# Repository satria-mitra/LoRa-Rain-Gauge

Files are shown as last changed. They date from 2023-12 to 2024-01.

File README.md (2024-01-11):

# <div style="text-align: center;" markdown="1">LoRa Rain Gauge</div>

This repository contains an Arduino sketch for a rain gauge system that utilizes LoRa communication, RTC for timestamping, and an SD card for data logging.

*CASA0016:MDB*\
Satria Mitra Utama

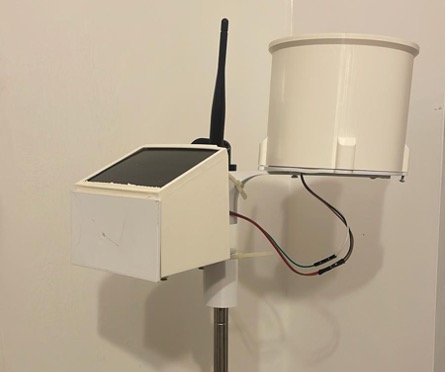
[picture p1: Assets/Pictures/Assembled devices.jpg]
Rain Gauge

# Dependancies
## Hardware Requirements
1. Arduino MKR board with LoRa connectivity
2. DS3231 RTC module
3. SD card module
4. Reed switch for rainfall measurement
5. 5mm Neodymum magnet
6. Printed Rain Gauge
7. 25mm screw with diameter 2mm
7. Lot of wires

### Optional Hardwares
1. Lipo Battery
2. Solar Panel
3. Adafruit Solar Charger

## Software
### Arduino Libraries
1. [RTCLib](https://www.arduino.cc/reference/en/libraries/rtclib/)
2. [MKRWAN](https://www.arduino.cc/reference/en/libraries/mkrwan/)
3. Wire
4. SD
5. SPI

### Node Red
1. [Node-Red Dashboard lib](https://flows.nodered.org/node/node-red-dashboard)

# Getting Started
1. **Connections**: Wire up the components according to the provided pin configurations. 

| No | Hardware | Hardware Pin | Arduino MKR Pin |
|----|---|---|---|
|1 | RTC | VCC |VCC |
| | | GND | GND |
| | | SCL | SCL/12 |
| | | SDA | SDA/11 |
|2 | Sd card  | VCC |VCC |
| | | GND | GND |
| | | MOSI | 8/MOSI |
| | | MISO | 10/MISO |
| | | SCK | 7 |
|3 | Reed switch| SW1 | 6 |
| | | VCC | VCC |
| | | GND | GND |
|4 | Charger | JST + | JST + |
| | | JST- | JST - |

2. **Rain Gauge**:
   - Print these files using PLA (not waterproof) or PETG(waterproof) filament 
     - rain_gauge-can.stl
     - rain_gauge-bucket.stl
     - rain_gauge-base.stl
   - Insert your 5mm neodymum magnet into the side hole of bucket
   - Use long shaft/screw to insert the bucket into the base
   - Plug the reed switch module into base. Final piece of Rain Gauge should looks like this
   
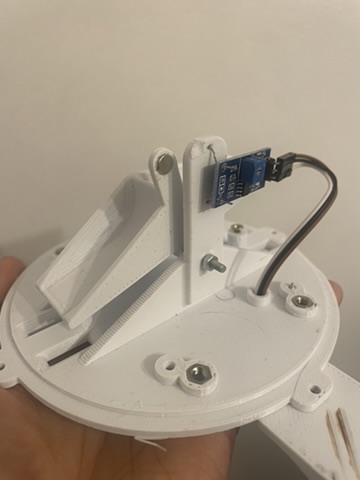
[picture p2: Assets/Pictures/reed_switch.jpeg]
   

2. **Libraries**: Install the necessary libraries (Wire, RTClib, MKRWAN, SPI, SD) in the Arduino IDE.
3. **TTN Application**:
   - Sign up for The Things Network
   - Select your region and [create your application on TTN console](https://www.thethingsindustries.com/docs/integrations/adding-applications/)
   - Plug your Arduino MKRWAN and run a script from Arduino IDE>Examples>MKRWAN>First Configuration, take a note on your DevUI
   - [Register your End Device on TTN Console ](https://workshops.cetools.org/codelabs/CASA0016-Workshop-4/index.html?index=..%2F..casa0016#6)
   - Create a file named __arduino_secrets.h__ on the same folder of Arduino LoRa Transmitter scripts and copy paste your appEui and appKey from TTN Console

     ```
     const char *appEui = "0000000000000000";
     const char *appKey = "<APP_KEY>";
     ``` 
4. Upload the scripts of Transmitter and see live data on TTN Console
5. If you can see your data, congratulations, if not please do see Troubleshooting sections
6. [Install Node-Red](https://nodered.org/docs/getting-started/) on your Raspberry PI or on your PC
7. [Install Node-Red Dashboard library](https://flows.nodered.org/node/node-red-dashboard)
8. Import Node-Red json files configuration from Scripts>Node-Red
9. See the payload on the debug message on Node-red. You can modify or create your own dashboard. Done

# Functionality
### RTC Setup
- Sets up and initializes the DS3231 RTC module for accurate timekeeping.
- Handles RTC power loss scenarios by setting the time using the sketch compilation time if power is lost.

### Rain Measurement
- Monitors rainfall using a reed switch and software debouncing to count pulses accurately.
- Resets accumulated rainfall at midnight to start afresh.

### LoRa Communication and Data Logging
- Sends rain gauge data via LoRaWAN to TTN at regular intervals.
- Logs data (date, time, accumulated rainfall) onto an SD card in a CSV format for local storage.

### Usage
- Monitor the Serial Monitor to observe real-time data and system status.
- Access the `rain.txt` file on the SD card for detailed logged rain gauge data.

## Troubleshooting
- If encountering issues during LoRa connection, ensure proper positioning for signal reception.
- Check your appKey and appEui on TTN Console and your aduino_secrets.h
- Verify wiring connections and component compatibility.
- Dont forget to attach your antenna

## Future Work
- Use low power library
- Design a watertight enclosure

## Reflective learning
- Prototype and iterate to make it better
- Outdoor device needs a waterproof and watertight material

## License
This project is licensed under the MIT License.

## Credits
- Dusan DJ for his awesome tipping buckets

## Acknowledgements
- Arduino community
- Libraries used: RTClib, MKRWAN, SD
- Node Red

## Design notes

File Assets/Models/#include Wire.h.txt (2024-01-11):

#include <Wire.h>
#include <RTClib.h>
#include <MKRWAN.h>
#include <ArduinoLowPower.h>
#include <SPI.h>
#include <SD.h>

// Secret file for storing AppEUI and Appkey of TTN App
#include "arduino_secrets.h"

#define debugSerial Serial

RTC_DS3231 rtc;

// SD card settings
const int chipSelect = 7 ;

// Reed Switch settings
const int reedSwitchPin = 4;
unsigned long lastDebounceTime = 0;
unsigned long debounceDelay = 150; // Adjusted according to pulse on Logic Analyzer

// Var for rain
const float rainTipVolume = 0.2; // mm
volatile int pulseCount = 0;
double   accumulatedRainfall = 0.0;

LoRaModem modem;

// Timer interval in milliseconds (60 seconds)
unsigned long previousMillis = 0;
const unsigned long interval = 600000;

// Variables to store the formatted date and time
char  formattedDate[11];
char  formattedTime[9];

File dataFile;

void setRTC() {
  if (! rtc.begin()) {
    Serial.println("Couldn't find RTC");
    Serial.flush();
    return;
  }

  if (rtc.lostPower()) {
    Serial.println("RTC lost power, let's set the time!");
    // When time needs to be set on a new device, or after a power loss, the
    // following line sets the RTC to the date & time this sketch was compiled
    rtc.adjust(DateTime(F(__DATE__), F(__TIME__)));
    // This line sets the RTC with an explicit date & time, for example to set
    // January 21, 2014 at 3am you would call:
    //rtc.adjust(DateTime(2023, 12, 10, 20, 12, 0));
  }
  // When time needs to be re-set on a previously configured device, the
  // following line sets the RTC to the date & time this sketch was compiled
   //rtc.adjust(DateTime(F(__DATE__), F(__TIME__)));
  // This line sets the RTC with an explicit date & time, for example to set
  // January 21, 2014 at 3am you would call:
  //rtc.adjust(DateTime(2023, 12, 13, 10, 38, 0));
}

void displayDateTime() {
  DateTime now = rtc.now();
  
  // Format date and time
  sprintf(formattedDate, "%04d-%02d-%02d", now.year(), now.month(), now.day());
  sprintf(formattedTime, "%02d:%02d:%02d", now.hour(), now.minute(), now.second());
     
  // Print JSON payload
  Serial.print("date :");
  Serial.println(formattedDate);
  Serial.print("time :");
  Serial.println(formattedTime);
}

void countPulse() {
  // Implement software debouncing
  if (millis() - lastDebounceTime > debounceDelay) {
    pulseCount++; // Increment the pulse count
    float rainCounted = pulseCount * rainTipVolume;
    pulseCount = 0;
    accumulatedRainfall += rainCounted;
    debugSerial.println(accumulatedRainfall);

  }
  lastDebounceTime = millis();
}

void resetRain() {
  DateTime now = rtc.now();
  if (now.hour() == 0 && now.minute() == 00 && now.second() == 0) {
  accumulatedRainfall = 0.0;
  }
}

void publishMessages() {
  DateTime now = rtc.now();
  // Format date and time
  sprintf(formattedDate, "%04d-%02d-%02d", now.year(), now.month(), now.day());
  sprintf(formattedTime, "%02d:%02d:%02d", now.hour(), now.minute(), now.second());

  uint16_t rainInt = accumulatedRainfall*10;

  // Payload message
  byte payload[4];
  payload[0] = highByte(rainInt);
  payload[1] = lowByte(rainInt);
  //payload[2] = highByte(formattedDate);
  //payload[3] = lowByte(formattedDate);

  debugSerial.print("Rain: ");
  debugSerial.print(accumulatedRainfall);
  debugSerial.print("mm at: ");
  debugSerial.print(formattedTime);
  debugSerial.print(" on ");
  debugSerial.println(formattedDate);

  // open the file. note that only one file can be open at a time,
  // so you have to close this one before opening another.
  dataFile = SD.open("rain.txt", FILE_WRITE);

  if (dataFile) {
    dataFile.print(formattedDate);
    dataFile.print(",");
    dataFile.print(formattedTime);
    dataFile.print(",");
    dataFile.println(accumulatedRainfall);
    Serial.println("Data saved");

    dataFile.close();
  } else {
    // if the file didn't open, print an error:
    Serial.println("error opening rain_gauge.txt");
  }

  modem.beginPacket();
  modem.write(payload, sizeof(payload));
  int err = modem.endPacket(true);
  if (err > 0) {
    Serial.println("Message sent correctly!");
  } else {
    Serial.println("Error sending message");
  }
}

void sendPayload() {
  DateTime now = rtc.now();
  if (now.second() == 0) {
    if (millis() - previousMillis >= interval || previousMillis == 0) {
      publishMessages();
      previousMillis = millis(); // Update the previousMillis variable
    }
  } else {
    previousMillis = 0; // Reset previousMillis if it's not at 00 seconds
  }
}
void initModem() {
  // change this to your regional band (eg. US915, AS923, ...)
  if (!modem.begin(EU868)) {
    Serial.println("Failed to start module");
  }

  Serial.print("Your device EUI is: ");
  Serial.println(modem.deviceEUI());

  int connected = modem.joinOTAA(appEui, appKey);
  if (!connected) {
    Serial.println("Something went wrong; are you indoor? Move near a window and retry");
  }
}

void initSDCard() {
  Serial.print("Initializing SD card...");

  if (!SD.begin(7)) {
    Serial.println("initialization failed!");
    return;
  }
  Serial.println("initialization done.");
}

void setup() {
  debugSerial.begin(9600);

    // Wait a maximum of 10s for Serial Monitor
  while (!debugSerial && millis() < 10000);

  initSDCard();
  initModem();
  setRTC();
  displayDateTime(); 
  pinMode(reedSwitchPin, INPUT_PULLUP);
  attachInterrupt(digitalPinToInterrupt(reedSwitchPin), countPulse, FALLING);

}

void loop() {
  // Your code might perform other tasks here, but for rain measurement, we'll focus on the interrupt
  sendPayload();
  resetRain();
  // We're relying on the interrupt to count rain pulses, so this loop might remain empty
}

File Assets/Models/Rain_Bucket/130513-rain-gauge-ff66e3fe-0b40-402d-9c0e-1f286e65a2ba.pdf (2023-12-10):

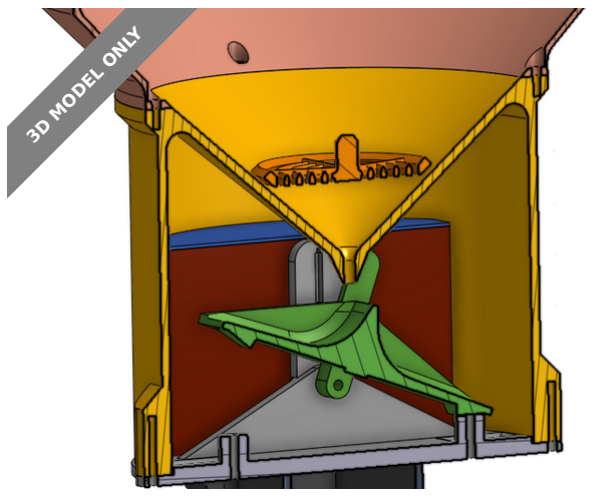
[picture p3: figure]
3D MODEL ONLY

## Summary

Tipping bucket rain gauge with reed switch contact for measuring rainfall

Hobby & Makers (https://www.printables.com/model?categoryId=48) | > | Electronics (https://www.printables.com/model?categoryId=52)
Tags: diy | sensor | rain | raingauge | tippingbucket

srazkomer

Print your own rain gauge for measuring rainfall. Add some microcontroller like arduino or esp and you can gather and chart the daily rainfall in home automation system like OpenHAB or HomeAsisstant.

Description

There are three options how to use it:

put microcontroller inside the can into inside box or
put microcontroller into outside box under the rain gauge or just use wiring from reed switch to microcontroller on better accessible place

Use round magnet 5x2mm together with magnetic reed switch to count impulses. One impuls from reed switch equals 0.2 mm of rainfall. It is possible to adjust the amount a bit with the adjusting screws under the bucket (see the picture)

DusanJ (https://www.printables.com/social/17868/about)

## Rain gauge

VIEW IN BROWSER (https://www.printables.com/model/130513-rain-gauge)

updated 27. 4. 2022 | published 7. 2. 2022

1.
2.
3.

# Model files

Printing tips

Everything is designed to be printed without supports. I recommend to use 0.6mm nozzle for bigger parts. I printed everything with PETG and then painted it with gray UV resistant color paint.

bucket - print on side with magnet holder
can - print upside down

Assembling

Screw the can with top ring with four M3x6 or M3x8. Glue the magnet into bucket, connect reed switch (be carefull not to brake it) and test if the bucket can move smoothly and if the switch is generating correct impulses.

At the end screw together the can with base with four M3x8 screws.

Don't forget to put the strainer into can to avoid jamming the small hole with leaves or insect.

•
•

rain_gauge-base.stl

rain_gauge-base-drop_edge.stl

rain_gauge-bucket.stl

rain_gauge-can.stl

# Other files

- MySensors (mysensors.org) based rain sensor adapted to work on battery
- MySensors (mysensors.org) based rain and anemometer sensor

rain_gauge-top_ring.stl

rain_gauge-holder_square_profile_20x20.stl

rain_gauge-box_outside.stl

rain_gauge-box_inside.stl

rain_gauge-box_inside_cap.stl

rain_gauge-strainer.stl

mysensorsrainbattery.ino

mysensorsanemorain.ino

## License

This work is licensed under a
Creative Commons (4.0 International License)

Attribution (http://creativecommons.org/licenses/by/4.0/)

✖ | Sharing without ATTRIBUTION
✔ | Remix Culture allowed
✔ | Commercial Use
✔ | Free Cultural Works
✔ | Meets Open Definition

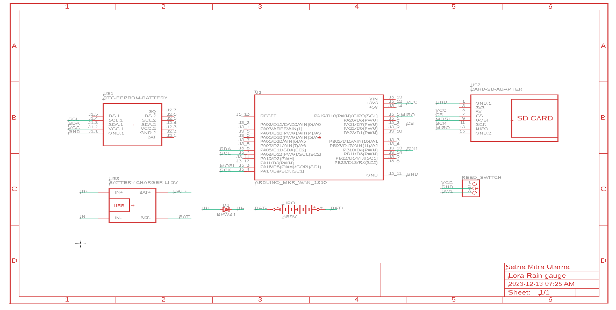
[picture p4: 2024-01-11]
Assets/Pictures/Schematics.png

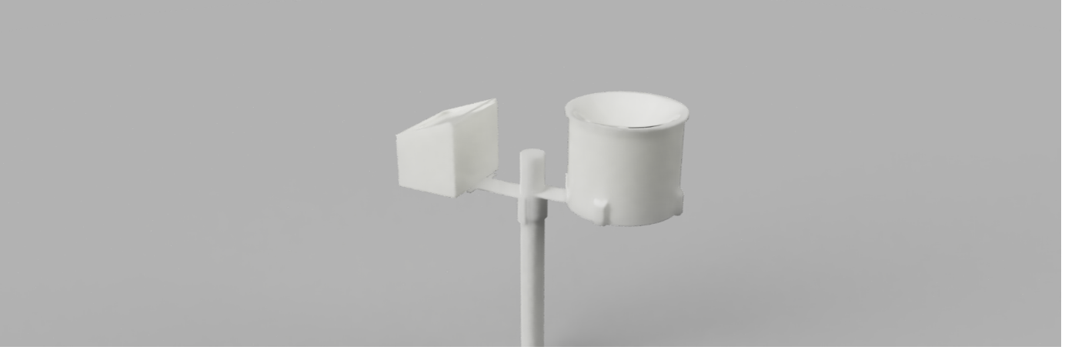
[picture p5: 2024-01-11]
Assets/Pictures/design concept.png

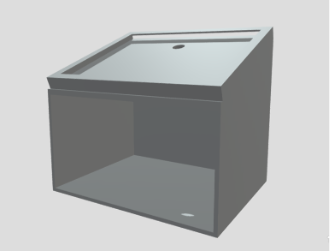
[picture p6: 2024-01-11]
Assets/Pictures/Enclosure.png

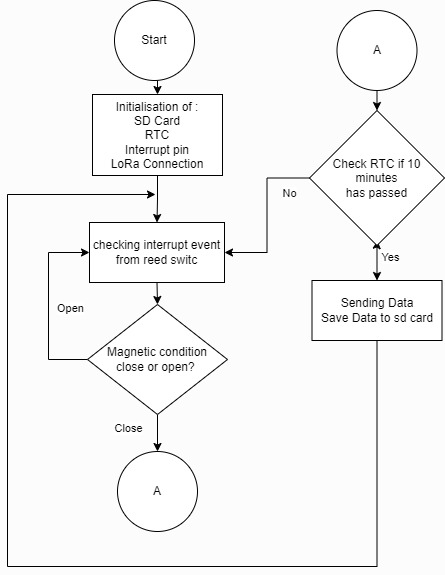
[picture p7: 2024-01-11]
Assets/Diagram/logic diagram (6).jpg

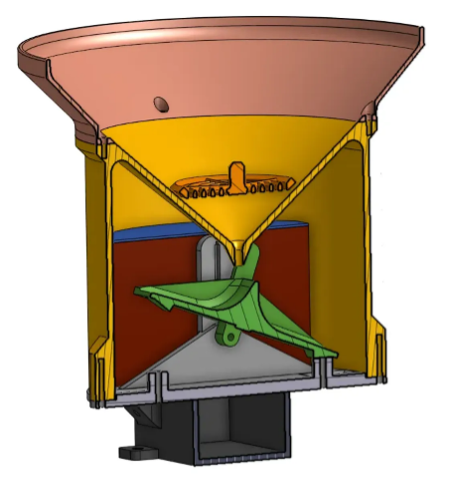
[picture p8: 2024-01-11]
Assets/Pictures/Tipping_bucket.png

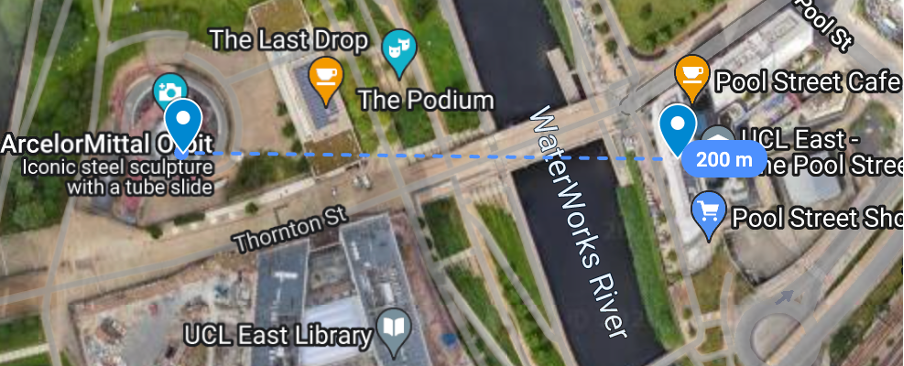
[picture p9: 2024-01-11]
Assets/Pictures/map.png

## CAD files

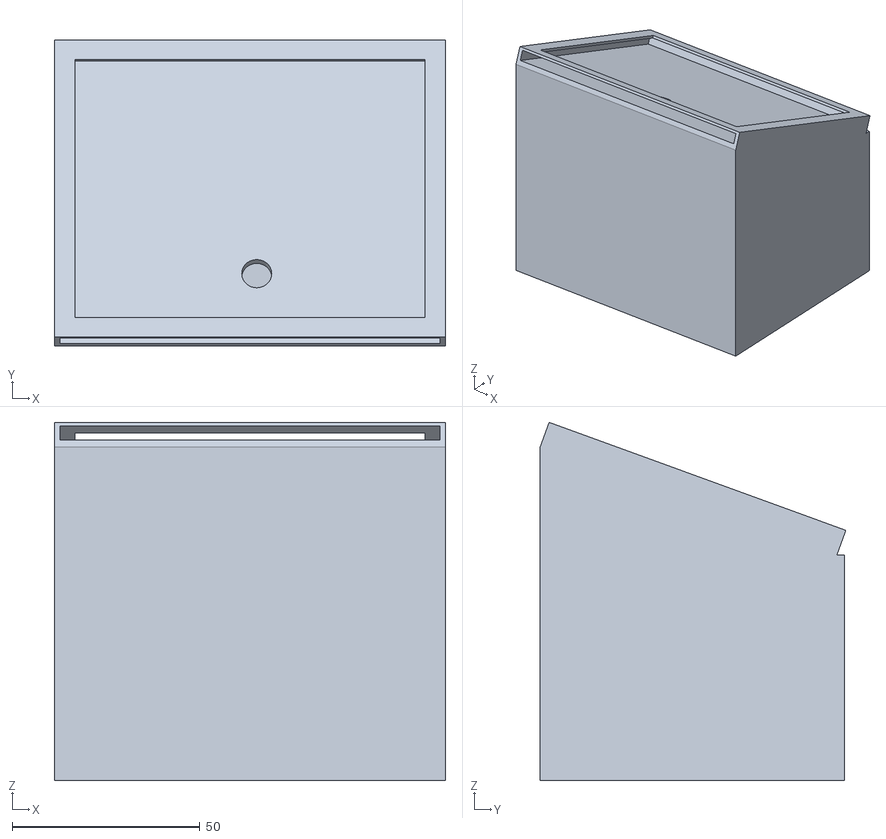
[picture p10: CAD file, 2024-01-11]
Assets/Models/Enclosures/enclosure v1.stl
104.0 x 81.3 x 95.3

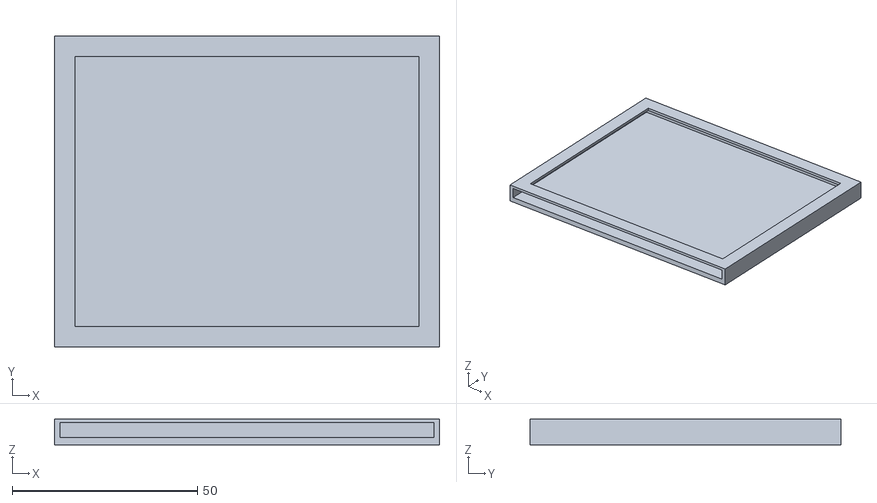
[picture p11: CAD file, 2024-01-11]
Assets/Models/Rain_Bucket/solar.stl
104.0 x 84.0 x 7.00

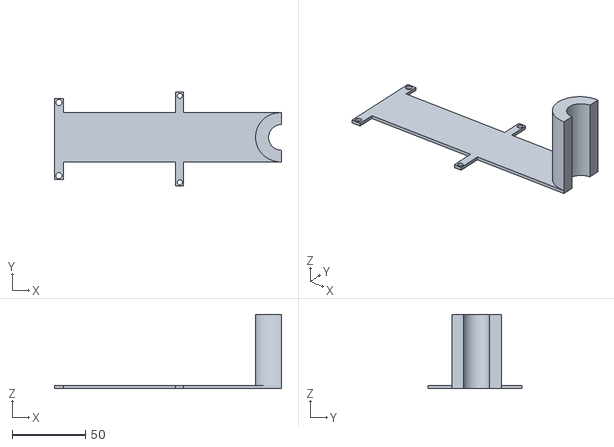
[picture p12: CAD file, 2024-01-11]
Assets/Models/Rain_Bucket/Body1.stl
154.9 x 64.0 x 50.5

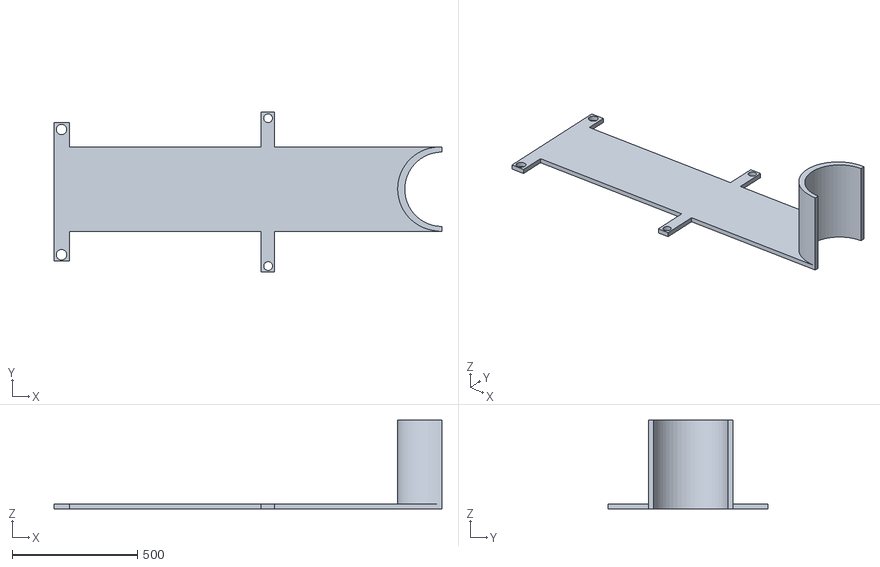
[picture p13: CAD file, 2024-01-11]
Assets/Models/Rain_Bucket/lengan_ff v1.stl
1549.0 x 640.0 x 355.0

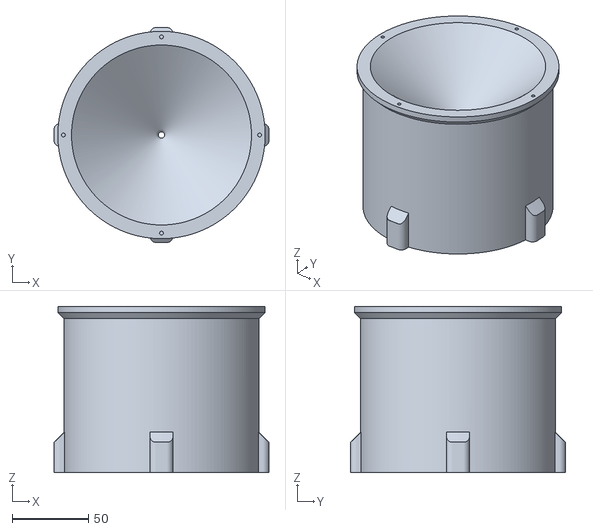
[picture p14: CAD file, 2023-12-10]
Assets/Models/Rain_Bucket/rain_gauge-can.stl
141.1 x 141.1 x 109.0

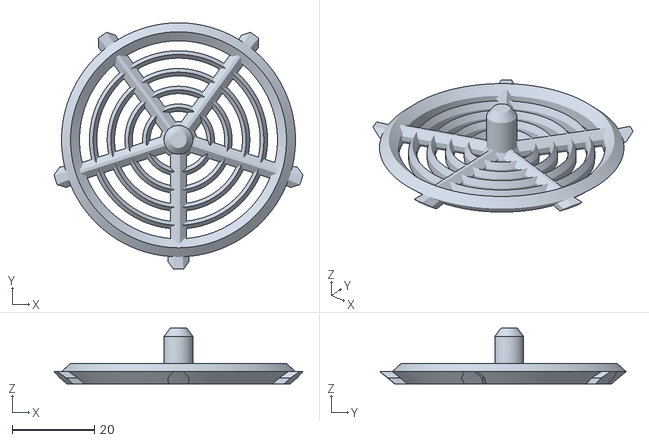
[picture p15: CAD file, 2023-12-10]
Assets/Models/Rain_Bucket/rain_gauge-strainer.stl
60.4 x 59.8 x 13.6

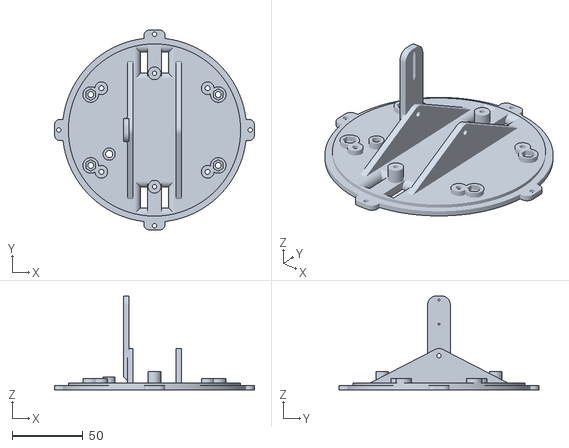
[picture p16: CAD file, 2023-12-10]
Assets/Models/Rain_Bucket/rain_gauge-base.stl
141.1 x 141.1 x 66.3

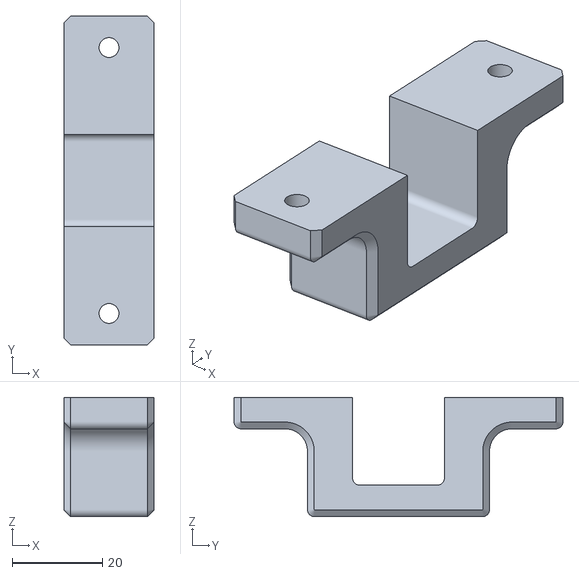
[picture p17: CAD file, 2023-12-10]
Assets/Models/Rain_Bucket/rain_gauge-holder_square_profile_20x20.stl
20.0 x 73.0 x 26.5

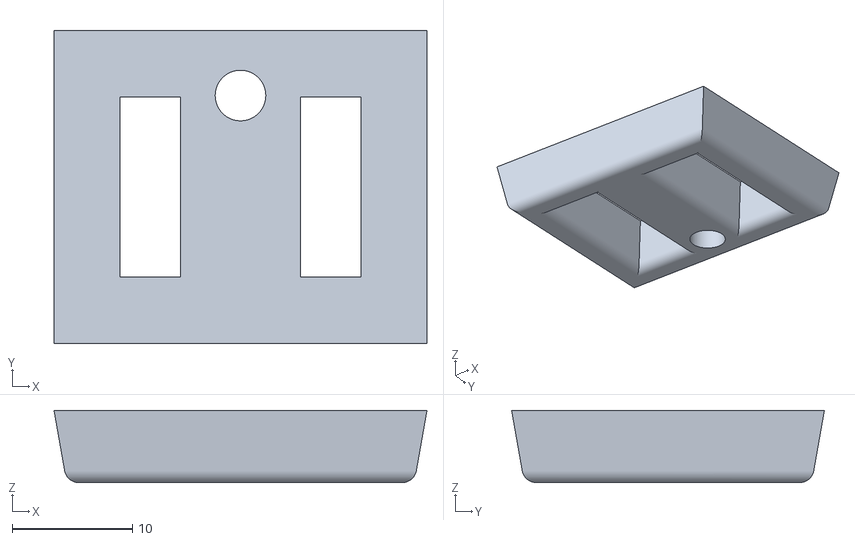
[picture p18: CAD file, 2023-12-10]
Assets/Models/Rain_Bucket/rain_gauge-base-drop_edge.stl
31.0 x 26.0 x 6.00

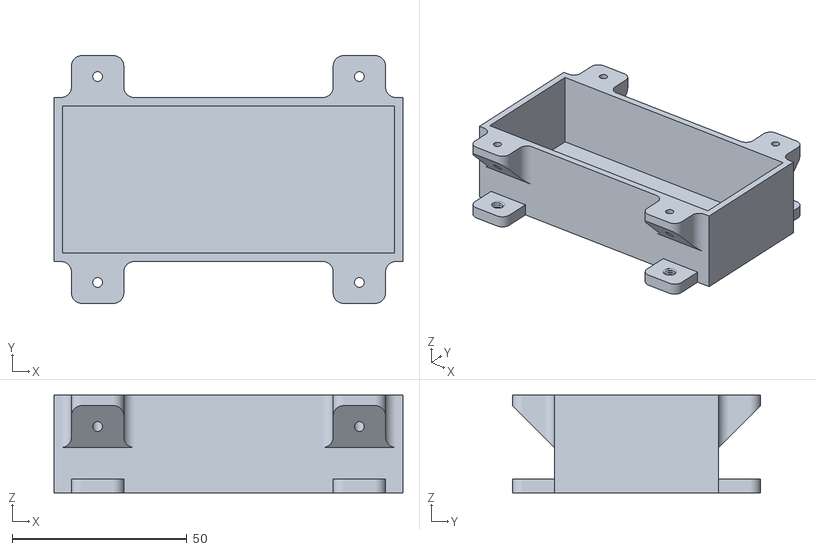
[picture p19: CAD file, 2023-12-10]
Assets/Models/Rain_Bucket/rain_gauge-box_outside.stl
100.0 x 71.0 x 28.0

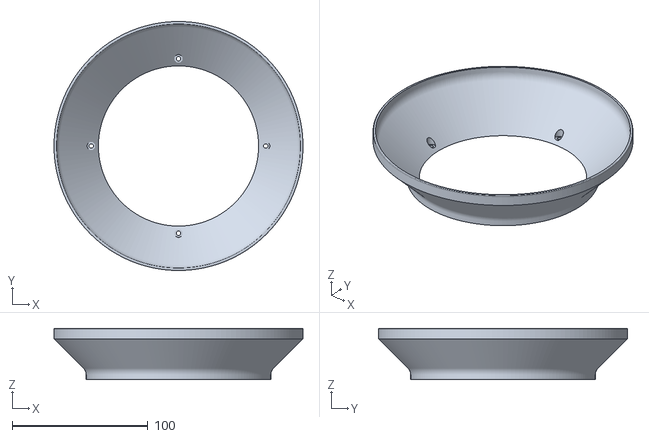
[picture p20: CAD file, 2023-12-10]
Assets/Models/Rain_Bucket/rain_gauge-top_ring.stl
183.6 x 183.6 x 37.9

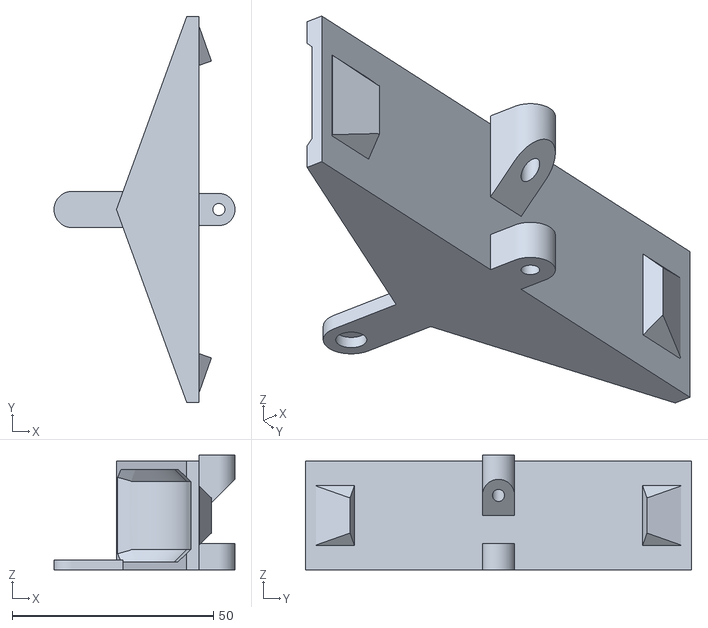
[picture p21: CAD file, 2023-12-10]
Assets/Models/Rain_Bucket/rain_gauge-bucket.stl
45.0 x 96.0 x 28.5

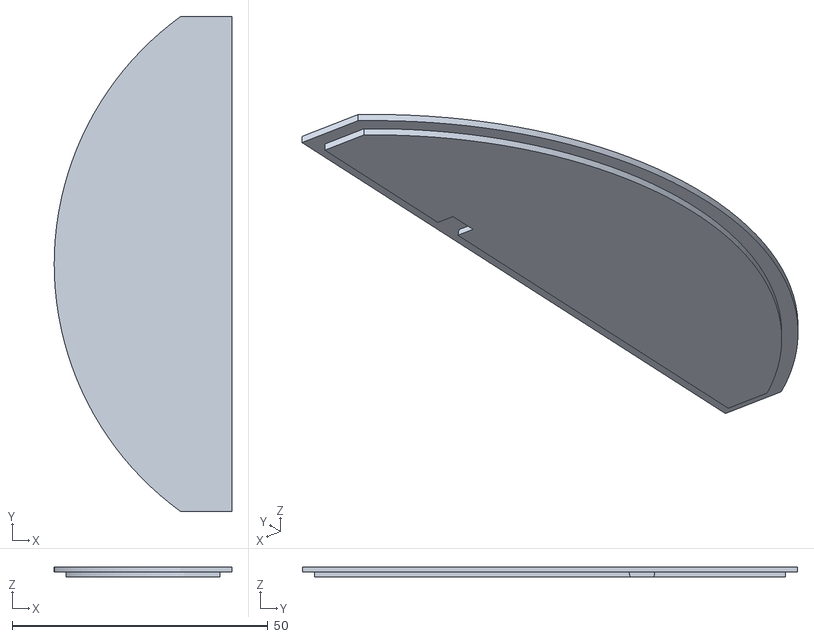
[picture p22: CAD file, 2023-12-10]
Assets/Models/Rain_Bucket/rain_gauge-box_inside_cap.stl
34.8 x 96.9 x 2.00

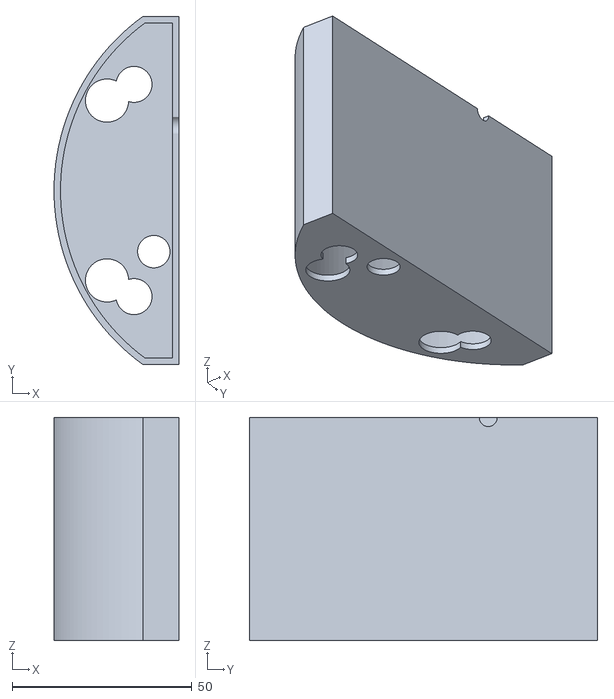
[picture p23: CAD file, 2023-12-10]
Assets/Models/Rain_Bucket/rain_gauge-box_inside.stl
34.8 x 96.9 x 62.0

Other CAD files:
Assets/Models/Rain_Bucket/lengan_ff v1.f3d
Assets/Models/Rain_Bucket/lengan_ff v2.f3d

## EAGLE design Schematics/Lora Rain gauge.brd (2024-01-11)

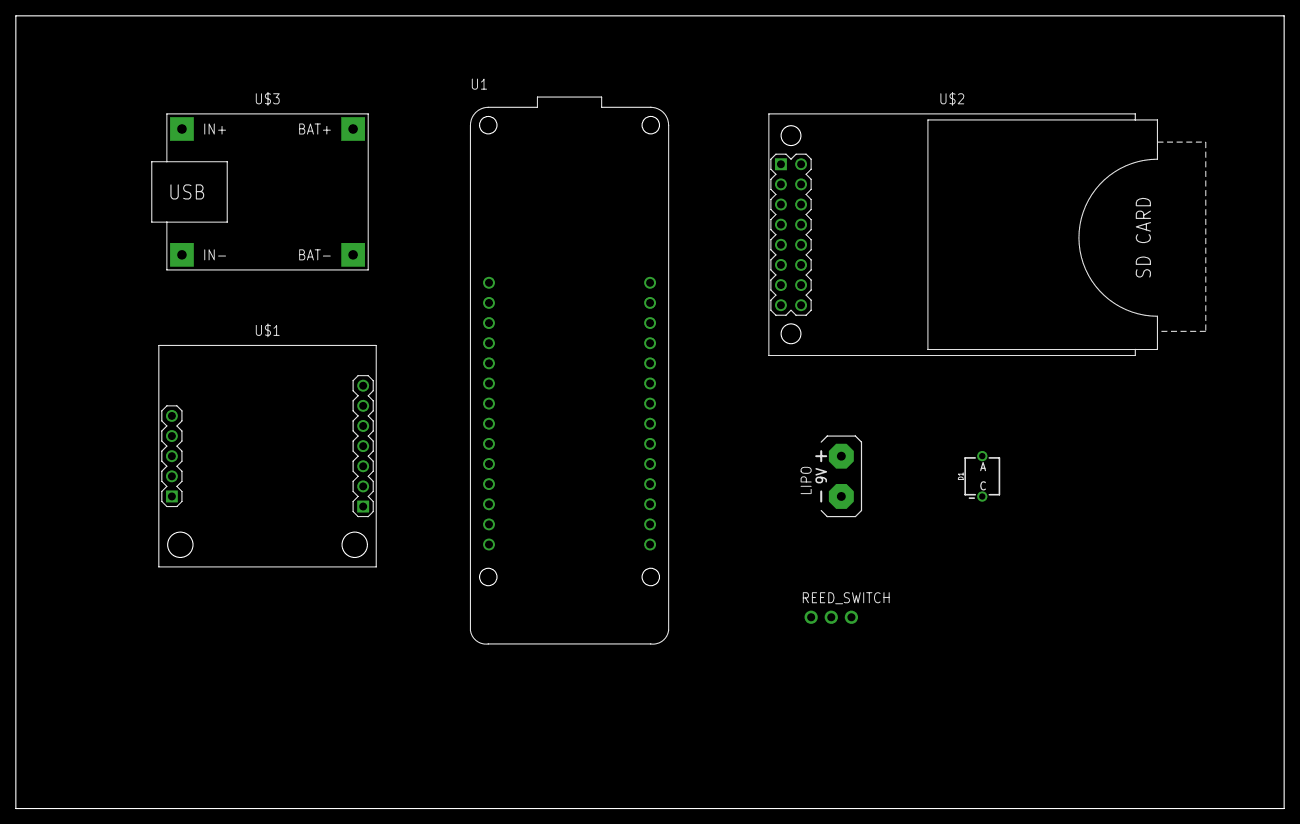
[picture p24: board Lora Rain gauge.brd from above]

Board: 2 copper layers, 160.0 x 100.0 mm, 7 parts (0 on the bottom side), 12 nets, no tracks yet.

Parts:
D1: BPW34
LIPO: AB9V
REED_SWITCH: 1X03-CLEANBIG
U1: ARDUINO_MKR_WAN_1310; BOARD_ARDUINO_MKR_WAN_1310
U$1: RTC-EEPROM-BATTERY; RTC_EEPROM_BATTERY
U$2: CARD-SD-ADAPTER
U$3: BATTERY-CHARGER-LI-5V

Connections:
BAT+: LIPO.+, U$3.BAT+
BAT-: LIPO.-, U$3.BAT-
CS: U1.J5_2, U$2.7
GND: REED_SWITCH.2, U1.J5_11, U$1.J1.1, U$2.1
GND.2: U$1.J2.2, U$2.15
MISO: U1.J5_5, U$2.13
MOSI: U1.J5_3, U$2.9
SCK: U1.J5_4, U$2.11
SCL: U1.J5_7, U$1.J1.4
SDA: U1.J5_6, U$1.J1.3
SW1: REED_SWITCH.3, U1.J3_13
VCC: REED_SWITCH.1, U1.J5_12, U$1.J1.2, U$2.5

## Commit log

2023-12-10 Upload 3d models of rain bucket
    [rain_gauge-base-drop_edge.stl, rain_gauge-base.stl, rain_gauge-box_inside.stl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]
2023-12-10 Add arduino secret for TTN App
2023-12-12 upload 3d file
    [Body1.stl, enclosure v1.stl, lengan_ff v1.f3d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]
2024-01-10 update github
    [rain-gauge (2).csv]
2024-01-10 [ImgBot] Optimize images
    *Total -- 1,157.80kb -> 1,006.51kb (13.07%)
    /Assets/Pictures/design concept.png -- 121.10kb -> 82.81kb (31.62%)
    /Assets/Pictures/Schematics.png -- 33.70kb -> 25.96kb (22.95%)
    /Assets/Pictures/Enclosure.png -- 23.55kb -> 18.55kb (21.25%)
    /Assets/Pictures/Node-red.png -- 11.07kb -> 8.78kb (20.69%)
    /Assets/Pictures/Tipping_bucket.png -- 188.55kb -> 153.94kb (18.35%)
    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
2024-01-11 upload the code and pictures
    [Body1.stl, enclosure v1.stl, lengan_ff v1.f3d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]
2024-01-11 upload schematics
    [Lora Rain gauge.brd, Lora Rain gauge.sch]

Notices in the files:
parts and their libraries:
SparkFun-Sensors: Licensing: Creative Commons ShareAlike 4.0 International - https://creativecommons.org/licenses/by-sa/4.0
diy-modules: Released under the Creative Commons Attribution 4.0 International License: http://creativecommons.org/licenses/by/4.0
